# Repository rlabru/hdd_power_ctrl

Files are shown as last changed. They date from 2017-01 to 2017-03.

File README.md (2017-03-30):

# hdd_power_ctrl

HDD power on/off from PC via arduino nano

Youtube video:

1. Making hardware part: https://youtu.be/gbGgRGde1ME

2. Making software part: https://youtu.be/tIniV0m-ixA

R.Lab_HDDPower_part1_rus.pdf - device assembly, Russian language.

HddPowerCtrl.ino - Adruino source file.

QtHddPower/ - folder with Qt project for software control power.

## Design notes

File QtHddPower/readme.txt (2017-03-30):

This is Qt project for support R.Lab video about HDD power control. Published here: https://youtu.be/tIniV0m-ixA

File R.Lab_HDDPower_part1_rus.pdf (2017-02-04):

Устройство для управления питанием жёсткого диска при помощи компьютера.

В этой статье мы расскажем о том, как изготовить устройство для управления питанием жёсткого диска при помощи компьютера. Оно будет включать в себя аппаратную и программную часть. К аппаратной части, собранной на базе платы Arduino, мы подключим жёсткий диск. Программная часть будет состоять из двух компонентов – код, заливаемый в микросхему ардуино и компьютерная программа, написанная на языке программирования С++ с использованием библиотеки QT. В ней будут только 2 кнопки – включение и выключение питания жёсткого диска.

Для того, чтобы собрать это устройство нам понадобятся следующие компоненты.

1) Сам демонстрационный жёсткий диск.

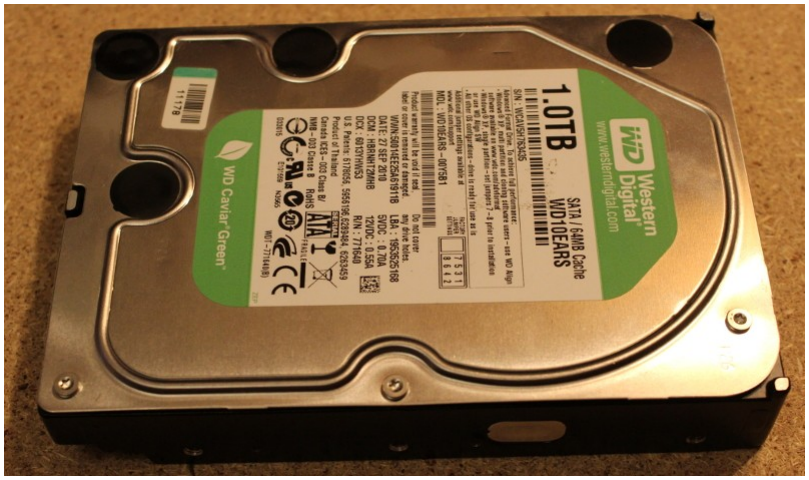
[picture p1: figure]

2) Плата Arduino NANO, которая будет управлять подачей питания на жёсткий диск. С одной стороны через USB она будет подключена к компьютеру, а с другой стороны будет управлять включением-выключением.

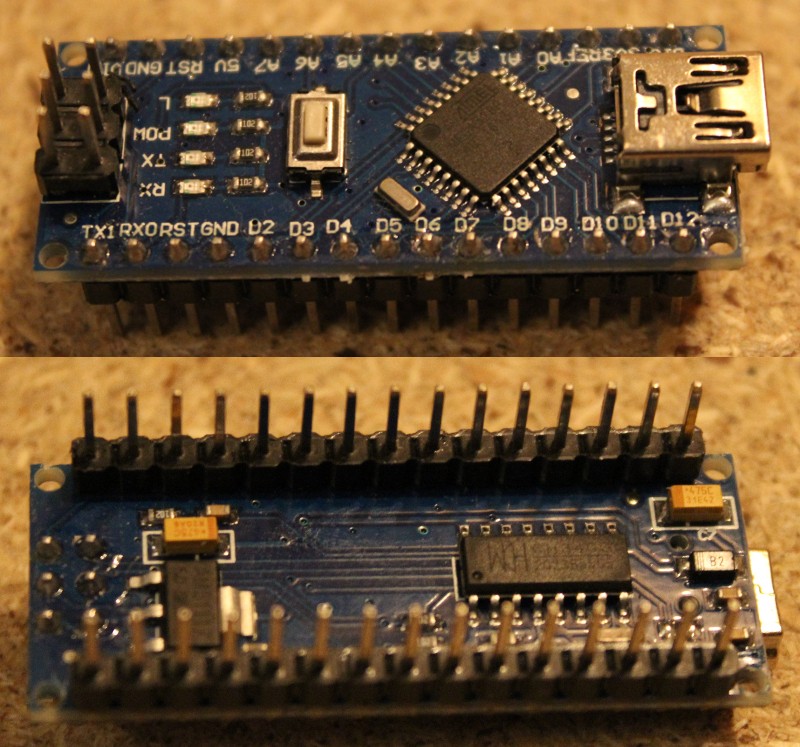
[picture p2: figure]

3) В качестве выключателей мы будем использовать два преобразователи напряжения. Это маленькие платы, преобразующие напряжение от 4В до 40 В, в регулируемое от 3В до 38В. Их можно купить в интернет-магазинах. Регулировка осуществляется при помощи переменного резистора.

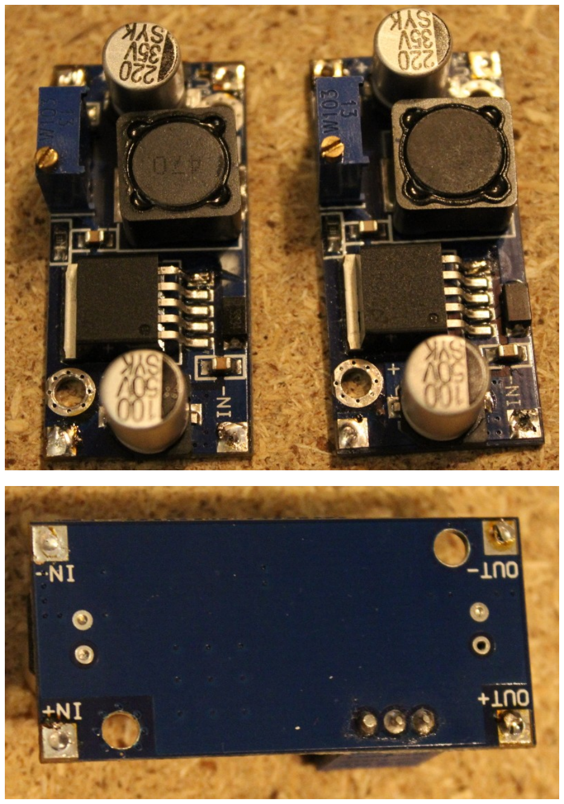
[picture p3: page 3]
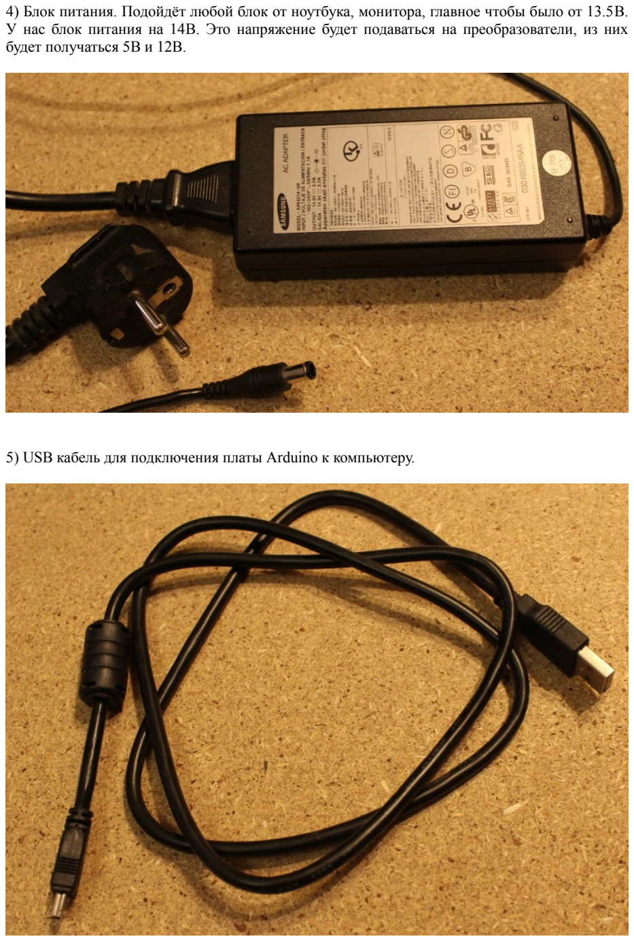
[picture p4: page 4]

4) Блок питания. Подойдёт любой блок от ноутбука, монитора, главное чтобы было от 13.5В. У нас блок питания на 14В. Это напряжение будет подаваться на преобразователи, из них будет получаться 5В и 12В.
5) USB кабель для подключения платы Arduino к компьютеру.

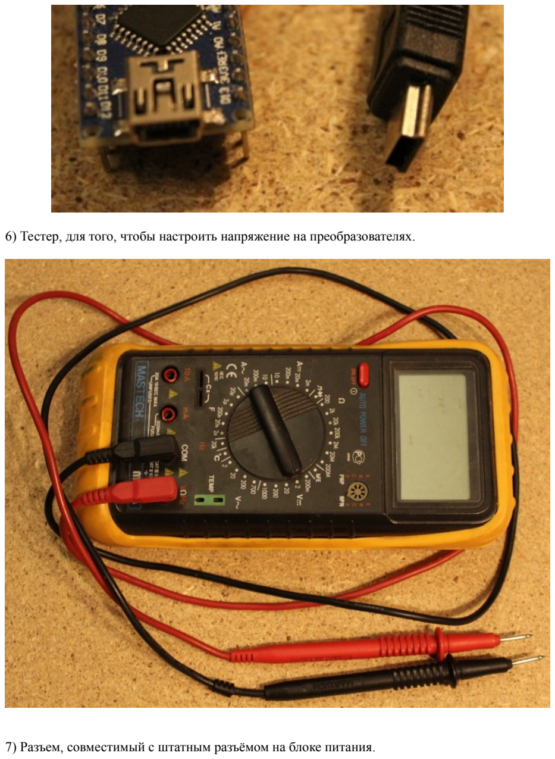
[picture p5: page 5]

6) Тестер, для того, чтобы настроить напряжение на преобразователях.
7) Разъем, совместимый с штатным разъёмом на блоке питания.

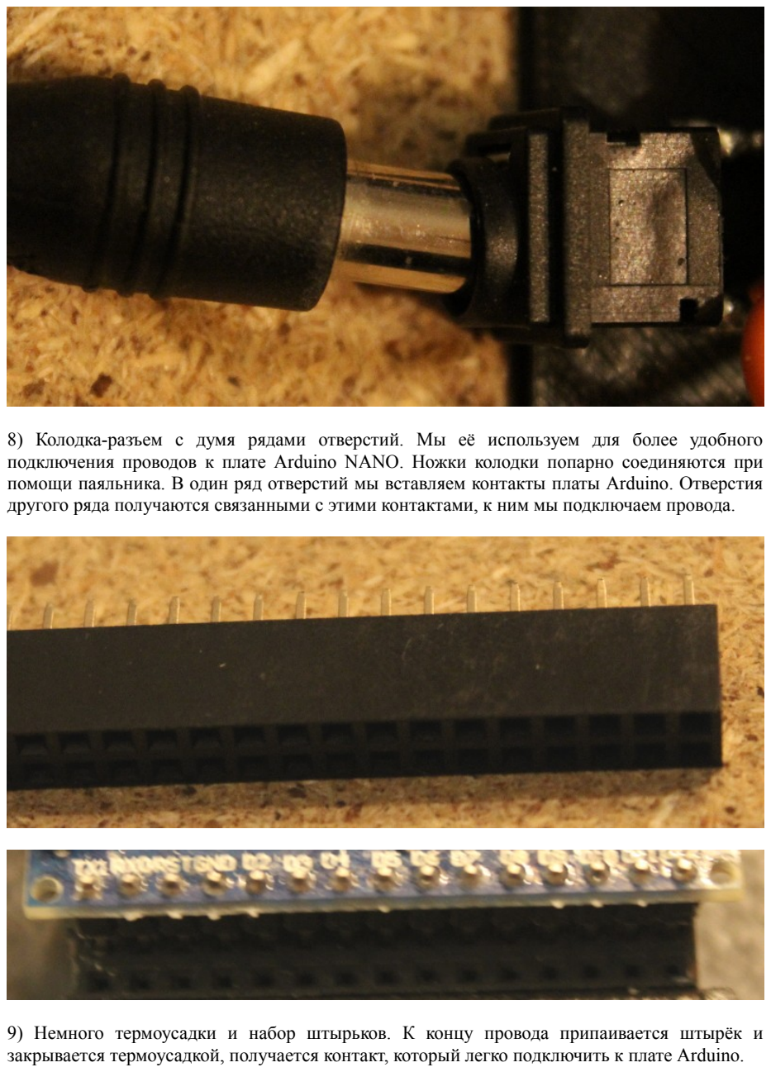
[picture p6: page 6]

8) Колодка-разъем с думя рядами отверстий. Мы её используем для более удобного подключения проводов к плате Arduino NANO. Ножки колодки попарно соединяются при помощи паяльника. В один ряд отверстий мы вставляем контакты платы Arduino. Отверстия другого ряда получаются связанными с этими контактами, к ним мы подключаем провода.
9) Немного термоусадки и набор штырьков. К концу провода припаивается штырёк и закрывается термоусадкой, получается контакт, который легко подключить к плате Arduino.

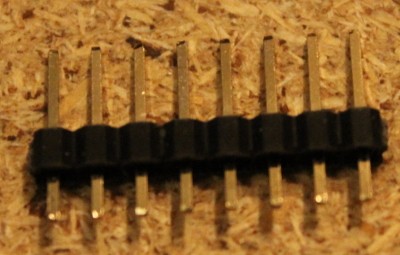
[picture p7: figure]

10) Резистор от 50 до 100 КОМ.
11) Набор винтиков.
12) Крепёжный элемент для фиксации вместе двух преобразователей напряжения и платы Arduino. Мы его изготовили сами, с помощью 3D принтера. На картинке он уже с приклеенными колодками-разъёмами. Ещё к нему приклеивается разъём от штатного блока питания.

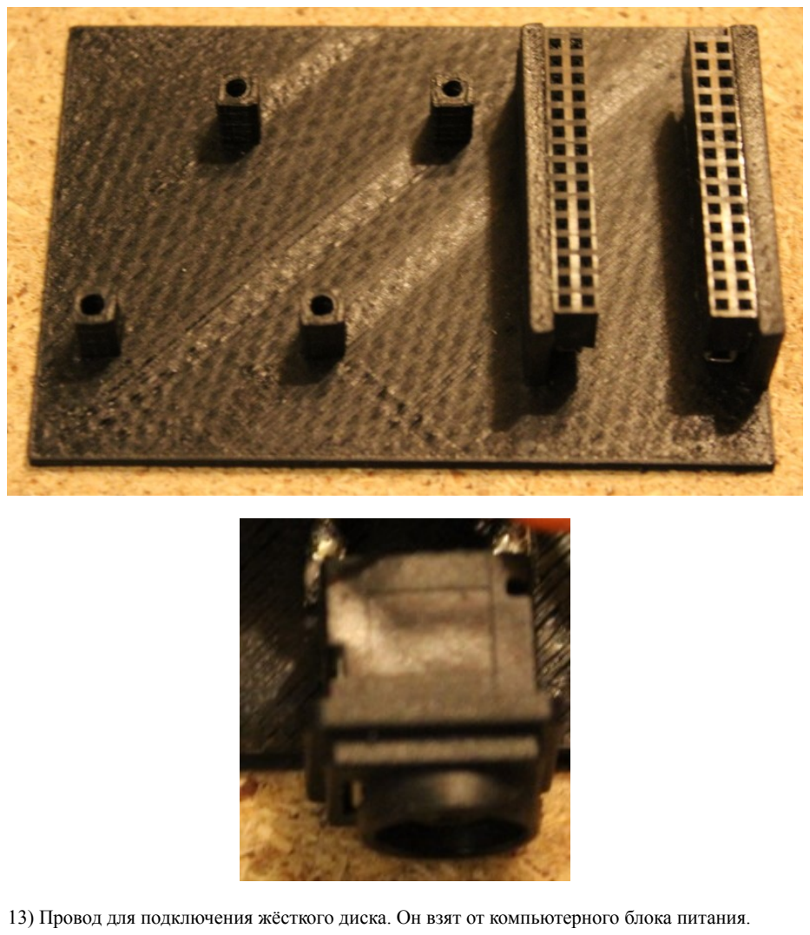
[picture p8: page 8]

13) Провод для подключения жёсткого диска. Он взят от компьютерного блока питания.

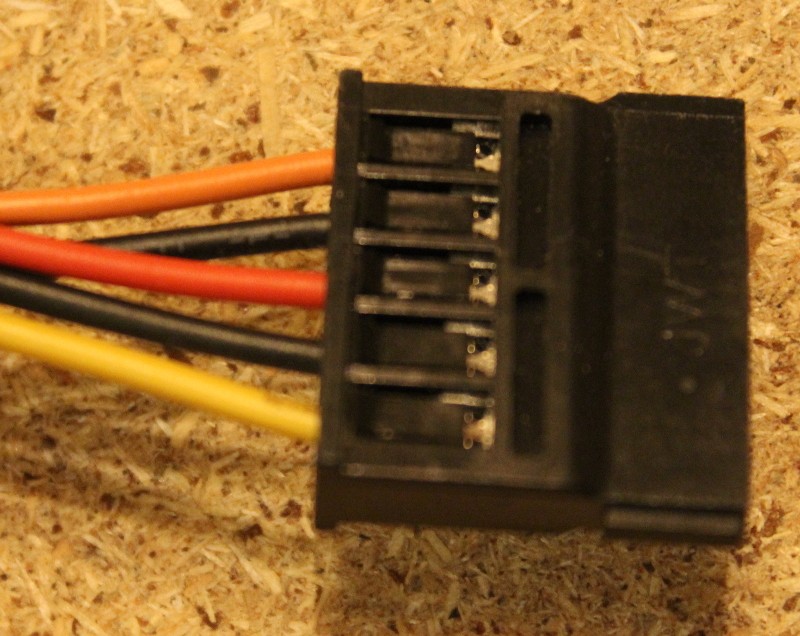
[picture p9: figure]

Сначала мы подготавливаем 2 колодки-разъемы, с количеством отверстий, равным контактам на плате Arduino так, как описанно в пункте 8. Попарно спаиваем ножки, с обратной стороны. Затем приклеиваем к крепёжному элементу и колодки и разъём питания.

Припаиваем провода к преобразователям и разъёму согласно схеме.

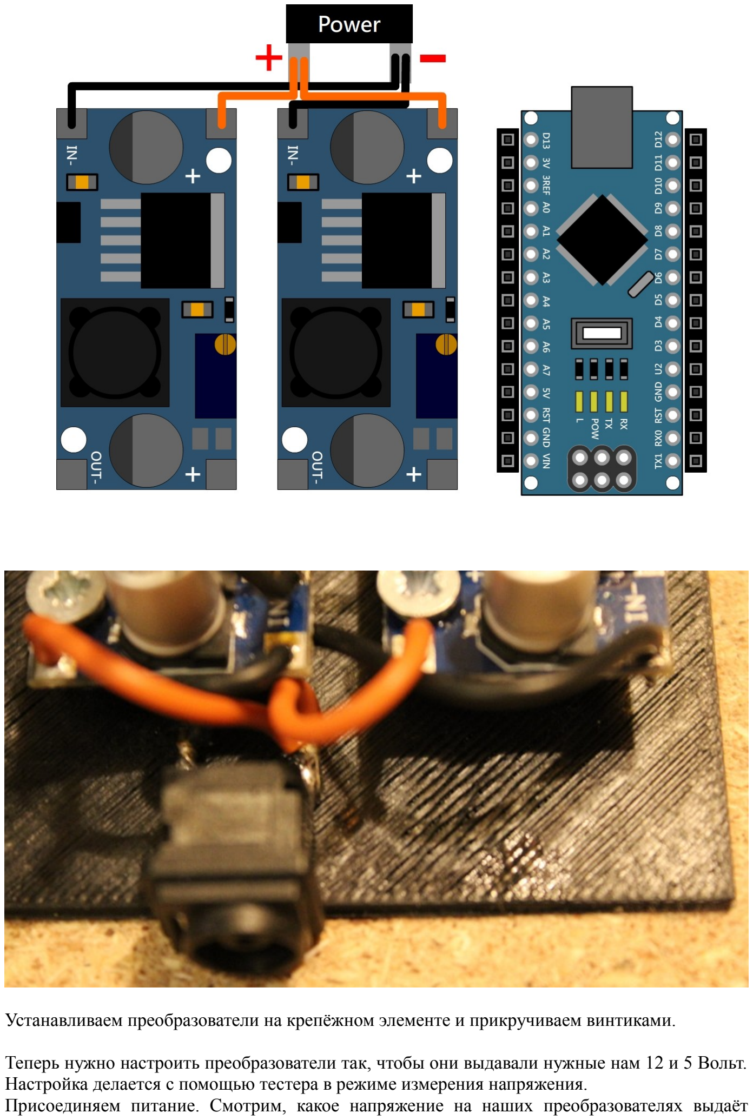
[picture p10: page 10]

Устанавливаем преобразователи на крепёжном элементе и прикручиваем винтиками.

Теперь нужно настроить преобразователи так, чтобы они выдавали нужные нам 12 и 5 Вольт. Настройка делается с помощью тестера в режиме измерения напряжения.
Присоединяем питание. Смотрим, какое напряжение на наших преобразователях выдаёт прибор. На каждой плате есть переменный резистор, значение которого можно подогнать под нужное нам при помощи отвёртки.

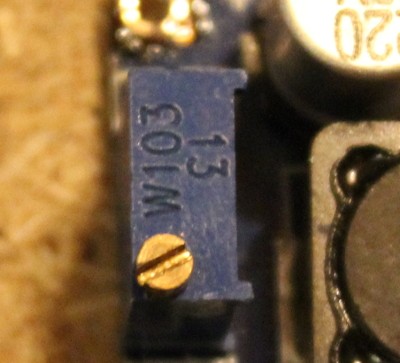
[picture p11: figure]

Крутим винтик отверткой и устанавливаем на одном преобразователе значение 5В, на другом 12В.

С другой стороны, к преобразователям припаивается разъём для подключения жёсткого диска. На нём 5 проводов. Желтый – это +12 В, два чёрных – это земля, красный – это +5 В, оранжевый – это 3.3 В. Оранжевый провод мы реализовывать не будем, так что просто обрежем его.
Остальные провода, припаиваем к преобразователям согласно схеме.

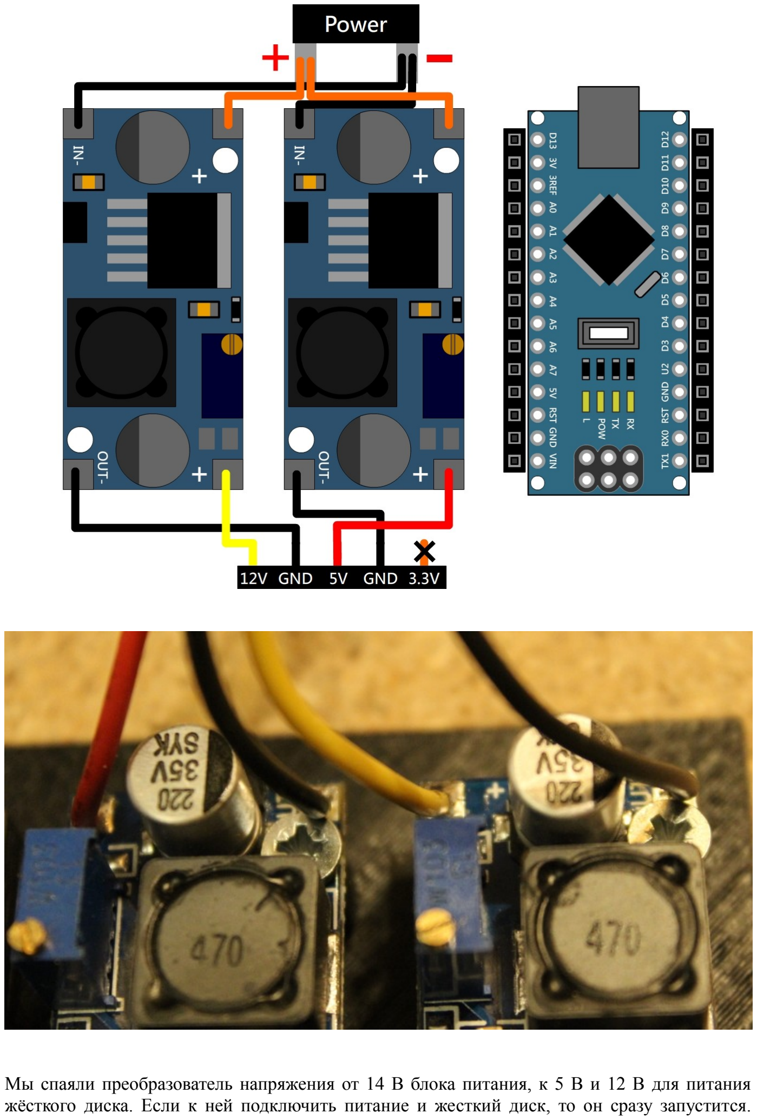
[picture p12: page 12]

Мы спаяли преобразователь напряжения от 14 В блока питания, к 5 В и 12 В для питания жёсткого диска. Если к ней подключить питание и жесткий диск, то он сразу запустится.

Можно это проверить.

Но нам нужно, чтобы включение-выключение диска управлялась из компьютера. Для этого задействуем функцию микросхемы, на которой основаны два преобразователя: "функцию электронного включения-выключения".
Ее обеспечивает пятый вывод микросхемы.

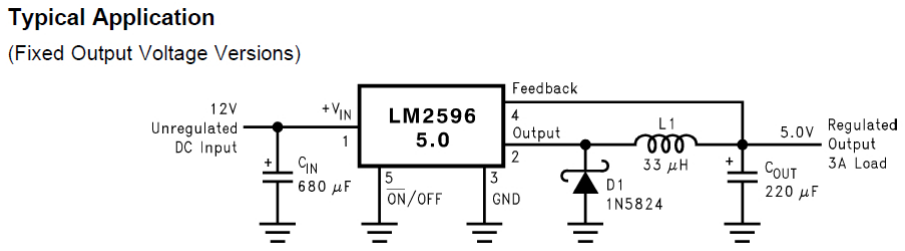
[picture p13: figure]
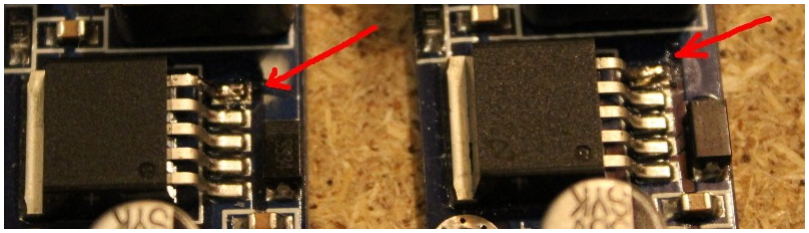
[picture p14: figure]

На преобразователях пятые выводы подключены к общему проводу. Это легко проверить тестером в режиме прозвона. Нам это не нужно, мы, с помощью паяльника приподнимаем и отгибаем обе пятые ножки и соединяем их проводами по схеме.

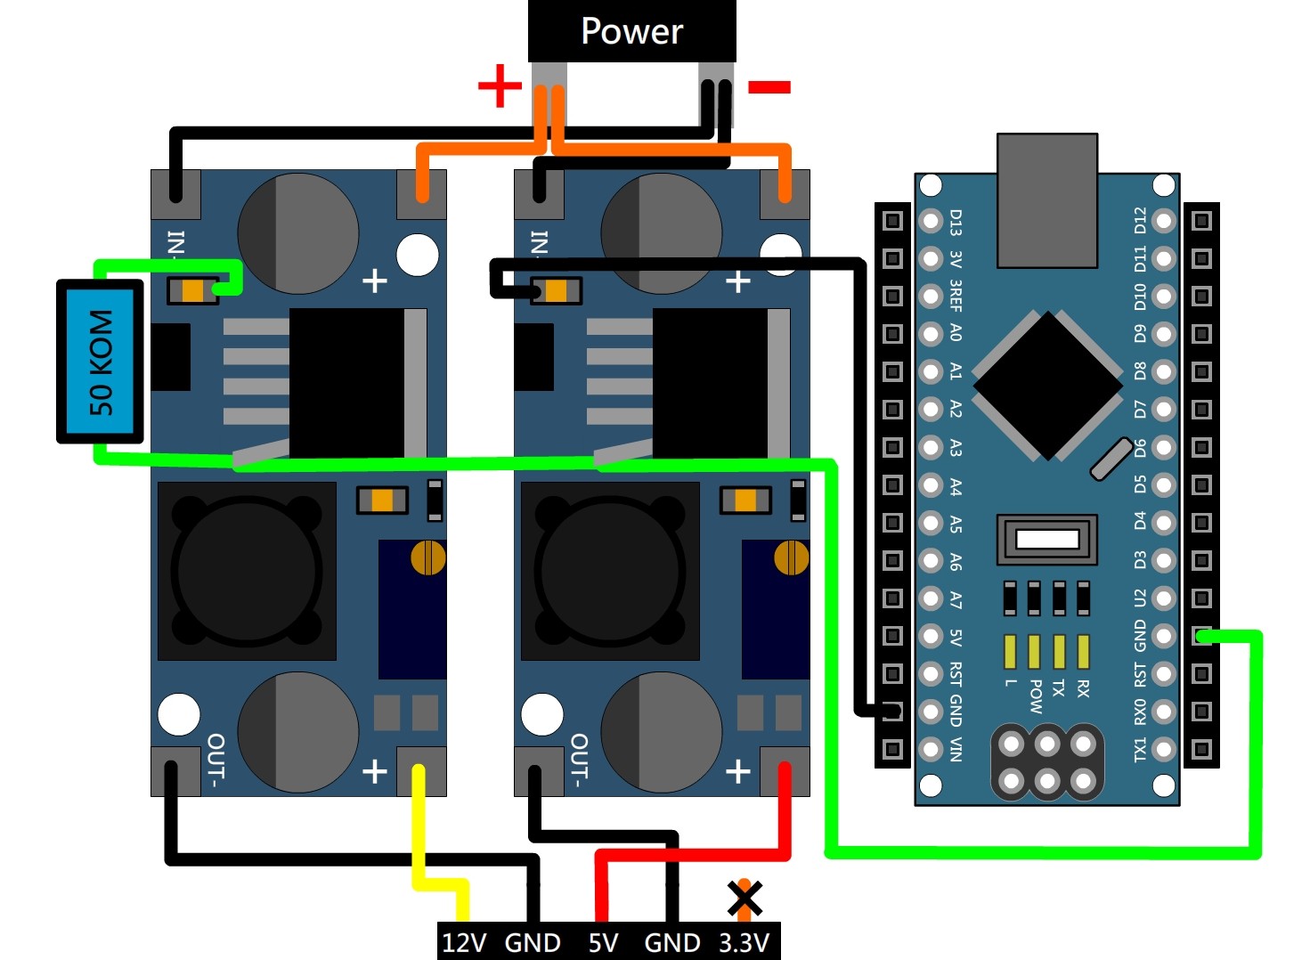
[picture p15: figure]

Оба вывода управления подключаем к земляным проводам Arduino, чтобы по включению напряжение подавалось. Резистор подключаем одной ножкой к плюсу входного напряжения, к которому удобно подключиться на ножке конденсатора, показанного на рисунке. Минус, который идет на Arduino, удобно взять с другой ножки конденсатора на второй плате, как на рисунке.

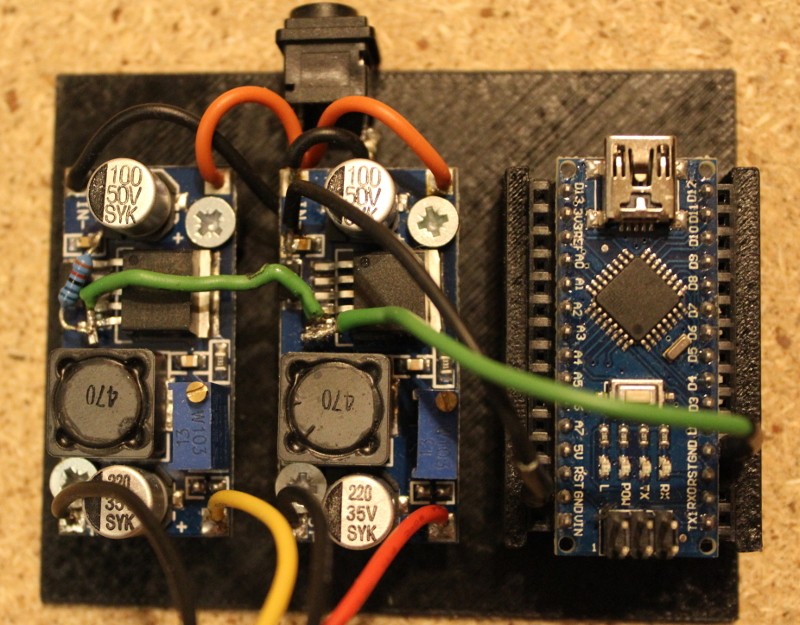
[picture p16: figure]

Схема собрана. Можно подключить жёсткий диск, питание и проверить, что когда мы замыкаем и чёрный провод и пятые выводы микросхем на землю – оба преобразователя запускаются и жёсткий диск начинает раскручиваться.

На этом первый этап создания устройства завершён. Следующим этапом у нас будет работа над программным кодом.

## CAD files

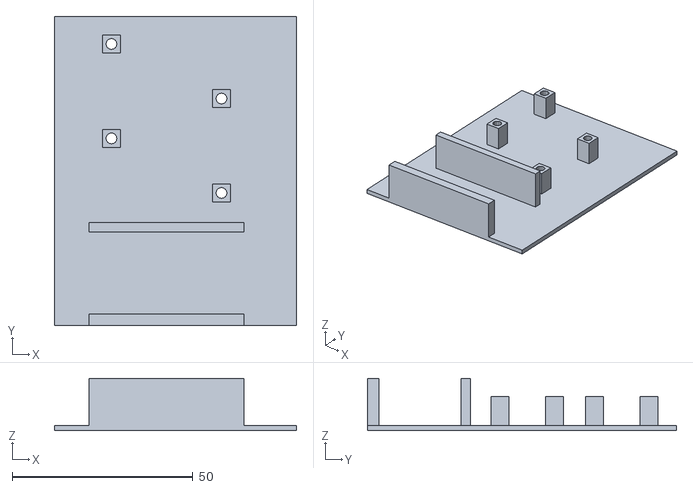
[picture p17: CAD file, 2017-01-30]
3d_print_src/ArduinoNANO2PowerCorpus.stl
67.0 x 85.5 x 14.5

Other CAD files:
3d_print_src/ArduinoNANO2PowerCorpus.blend

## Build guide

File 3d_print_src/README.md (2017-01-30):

# 3D print files

ArduinoNANO2PowerCorpus.blend - Blender 3D source file

ArduinoNANO2PowerCorpus.stl - device package STL file for 3D printing

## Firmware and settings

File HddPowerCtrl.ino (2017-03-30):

#define power_control_pin 2 // D2

void setup() {
  pinMode(power_control_pin, OUTPUT);
  digitalWrite(power_control_pin, HIGH);
  Serial.begin(9600);
}

void loop() {
  if(Serial.available() > 0) {
    char ctrl = Serial.read();
    if(ctrl== 'p') digitalWrite(power_control_pin, LOW);
    if(ctrl== 'o') digitalWrite(power_control_pin, HIGH);
  }
}
